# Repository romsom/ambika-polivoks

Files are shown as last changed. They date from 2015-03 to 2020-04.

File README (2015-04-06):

Polivoks voicecard for the Mutable Instruments Ambika synthesizer.

Based on work by Olivier Gillet - http://www.mutable-instruments.net/.

Developed by Krzysztof Iwanowski.

The firmware is released under a GPL3.0 license.

The PCB layouts and schematics are released under a Creative Commons cc-by-sa 3.0 license.

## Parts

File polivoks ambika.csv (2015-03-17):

Parts | Device | Value | Qty
LED1, LED2 | LED3MM |  | 2
JP1, JP3 | Male 1x3 header |  | 2
JP2, JP4 | Female 1x6 header |  | 2
R9, R10, R12, R21 | R | 100k | 4
R1, R15, R39 | R | 10k | 3
R2, R11 | R | 15k | 2
R8, R14 | R | 1k | 2
R13, R19, R22 | R | 2.2k | 3
R34, R37, R38 | R | 220 | 3
R23 | R | 33k | 1
R35, R36 | R | 470 | 2
R6, R7, R18, R20 | R | 47k | 4
R17 | R | 56k | 1
R16 | R | 68k | 1
C3, C5, C6, C7, C8, C9, C13, C14, C16, C17, C18, C23, C24, C25 | Ceramic | 100n | 14
C10 | Ceramic | 100p | 1
C11, C20, C28 | Electrolytic, >= 15V, height <= 7mm | 100u | 3
C26, C27 | Ceramic | 20p | 2
C2, C12 | Ceramic | 33n | 2
C1, C4 | Electrolytic NP, >35V | 4.7u | 2
Q5 | Quartz | 20MHz | 1
Q3, Q4 | 2N3904 NPN |  | 2
Q1, Q2 | 2N3906 PNP |  | 2
IC2 | 4052N |  | 1
IC7 | ATMega328p |  | 1
IC11 | LM13700N |  | 1
IC9, IC10 | LM4250P |  | 2
IC6 | MCP4822 |  | 1
IC5 | TL072P |  | 1
IC1 | TL084P |  | 1
 | DIP8 Socket |  | 4
 | DIP28 Socket |  | 1
 | DIP14 Socket |  | 1
 | DIP16 Socket |  | 2
 | Jumper |  | 2

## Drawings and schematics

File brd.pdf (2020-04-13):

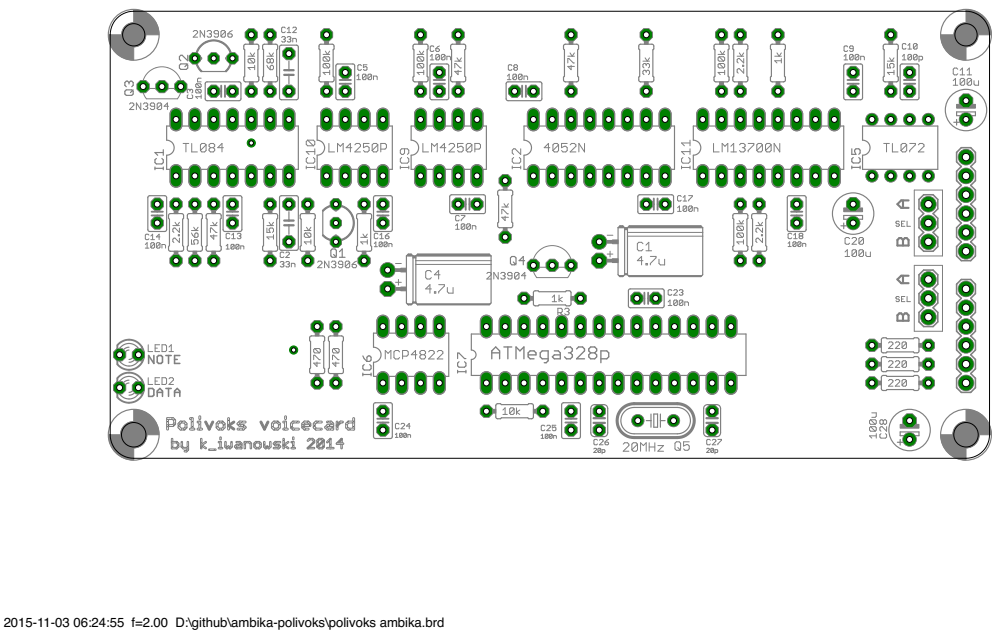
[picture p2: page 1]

2015-11-03 06:24:55 f=2.00 D:\github\ambika-polivoks\polivoks ambika.brd

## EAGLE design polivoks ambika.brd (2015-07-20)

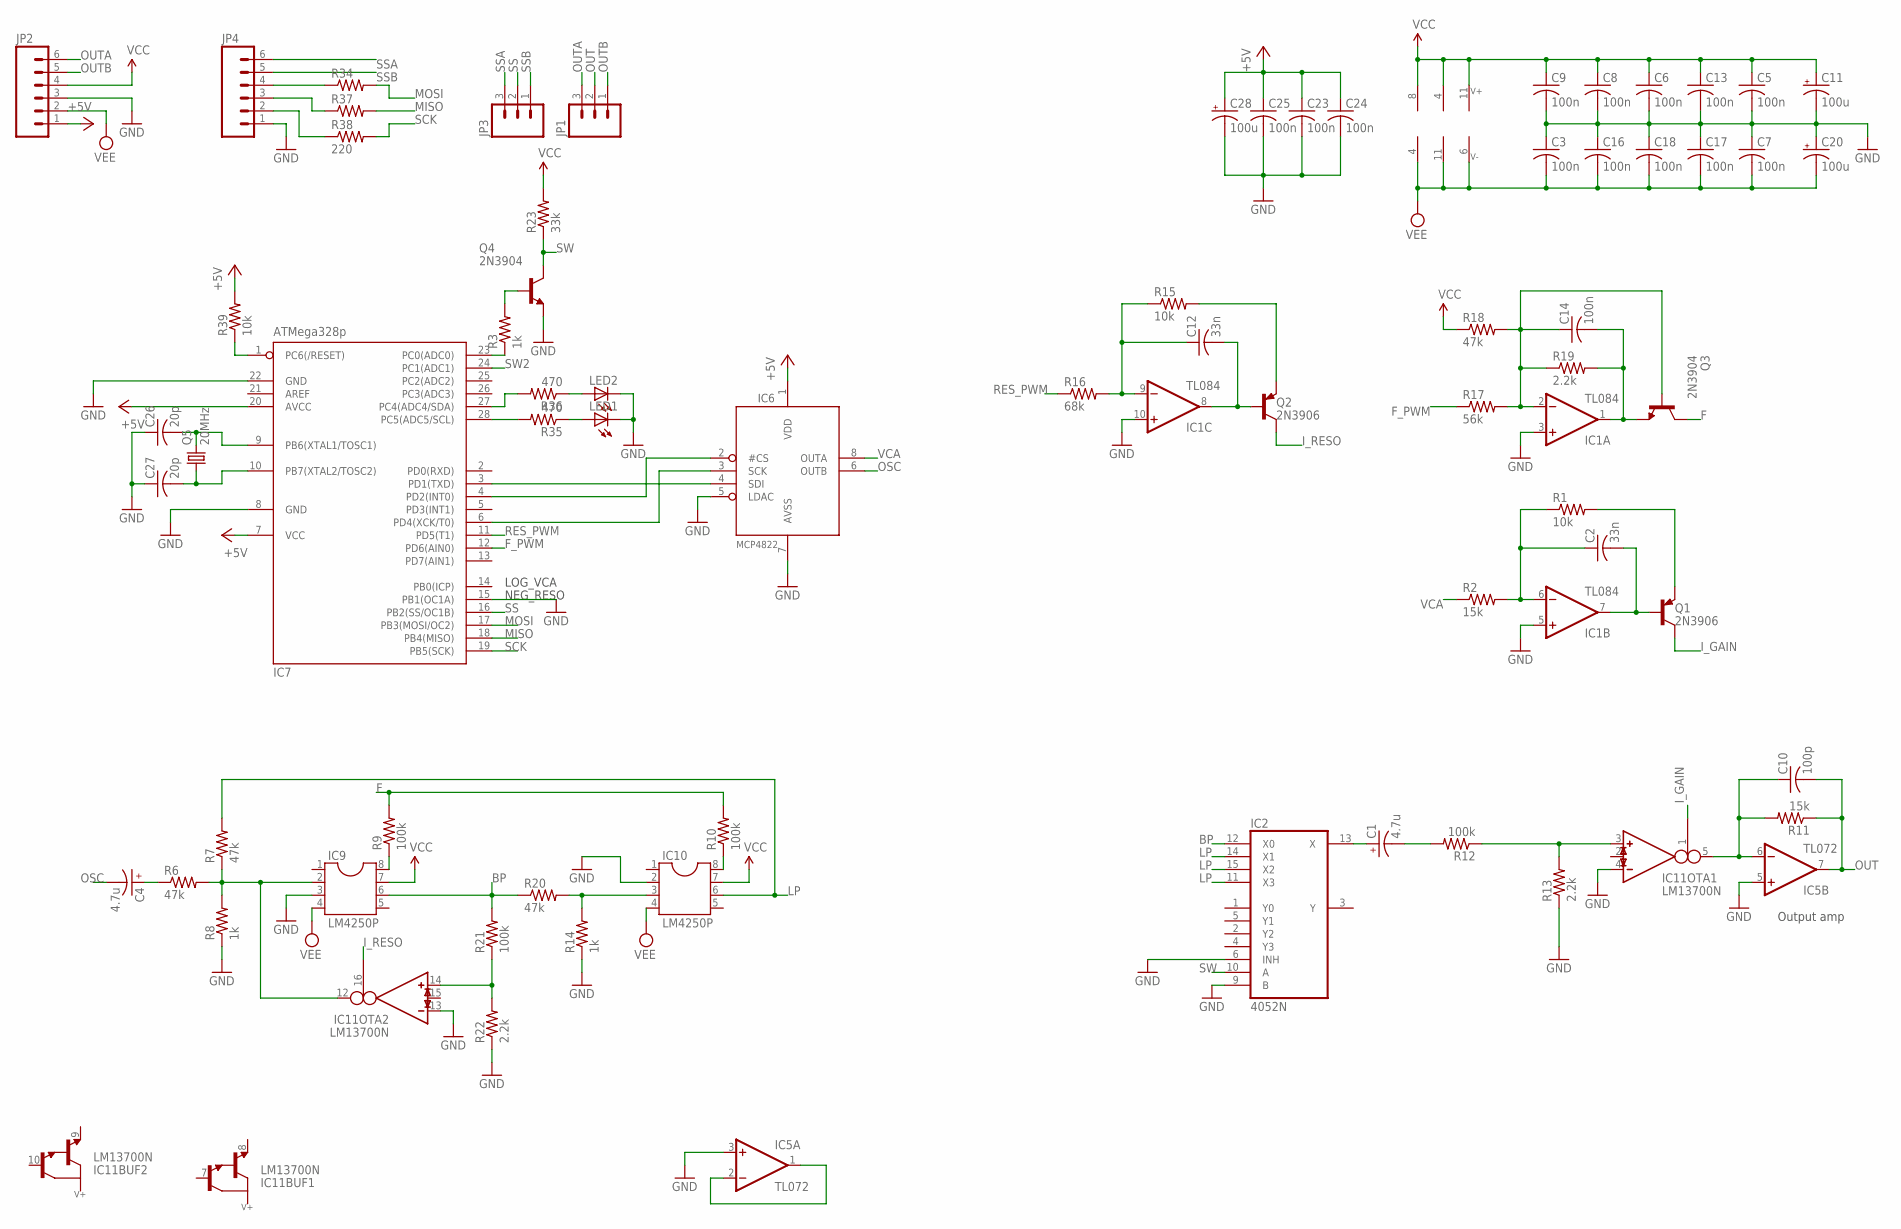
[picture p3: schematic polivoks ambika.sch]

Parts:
C1, C4: 4.7u; E11-6.3
C2, C12: 33n; C050-025X075
C3, C5, C6, C7, C8, C9, C13, C14, C16, C17, C18, C23, C24, C25: 100n; C025-025X050
C10: 100p; C025-025X050
C11, C20, C28: 100u; E2,5-6
C26, C27: 20p; C025-024X044
IC1: TL084; DIL14
IC2: 4052N; DIL16
IC5: TL072; DIL08
IC6: MCP4822; DIL08
IC7: ATMega328p; DIL28-3
IC9, IC10: LM4250P; DIL08
IC11: LM13700N; DIL16
JP1, JP3: M03PTH; 1X03
JP2, JP4: M06SIP; 1X06
LED1, LED2: LED3MM
Q1, Q2: 2N3906; TO92-
Q3, Q4: 2N3904; TO92
Q5: 20MHz; HC49U-V
R1, R15, R39: 10k; 0204/7
R2, R11: 15k; 0204/7
R3, R8, R14: 1k; 0204/7
R6, R7, R18, R20: 47k; 0204/7
R9, R10, R12, R21: 100k; 0204/7
R13, R19, R22: 2.2k; 0204/7
R16: 68k; 0204/7
R17: 56k; 0204/7
R23: 33k; 0204/7
R34, R37, R38: 220; 0204/7
R35, R36: 470; 0204/7

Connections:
+5V: C23.1, C24.1, C25.1, C28.+, IC6.1 (VDD), IC7.7 (VCC), IC7.20 (AVCC), JP2.1, R39.2
BP: IC2.12 (X0), IC9.6, R20.1, R21.2
F: Q3.1 (C), R9.2, R10.2
F_PWM: IC7.12 (PD6(AIN0)), R17.1
GND: C3.1, C5.2, C6.2, C7.1, C8.2, C9.2, C11.-, C13.2, C16.1, C17.1, C18.1, C20.+, C23.2, C24.2, C25.2, C26.1, C27.1, C28.-, IC1.3 (+IN), IC1.5 (+IN), IC1.10 (+IN), IC2.6 (INH), IC2.8 (GND), IC2.9 (B), IC5.3 (+IN), IC5.5 (+IN), IC6.5 (LDAC), IC6.7 (AVSS), IC7.8 (GND), IC7.15 (PB1(OC1A)), IC7.22 (GND), IC9.3, IC10.2, IC11.4 (IN_N), IC11.13 (IN_N), JP2.3, JP4.1, LED1.K (C), LED2.K (C), Q4.3 (E), R8.1, R13.1, R14.1, R22.1
I_GAIN: IC11.1 (I_BIAS), Q1.1 (C)
I_RESO: IC11.16 (I_BIAS), Q2.1 (C)
LP: IC2.11 (X3), IC2.14 (X1), IC2.15 (X2), IC10.6, R7.2
MISO: IC7.18 (PB4(MISO)), R37.2
MOSI: IC7.17 (PB3(MOSI/OC2)), R34.2
unnamed: IC9.2, IC11.12 (OUT), R6.2, R7.1, R8.2
unnamed: C14.2, IC1.1 (OUT), Q3.3 (E), R19.2
unnamed: IC6.4 (SDI), IC7.3 (PD1(TXD))
unnamed: C4.+ (1), R6.1
unnamed: C1.+ (1), IC2.13 (X)
unnamed: IC10.3, R14.2, R20.2
unnamed: LED1.A, R35.1
unnamed: JP4.2, R38.1
unnamed: IC9.8, R9.1
unnamed: LED2.A, R36.1
unnamed: IC7.27 (PC4(ADC4/SDA)), R36.2
unnamed: C1.- (2), R12.2
unnamed: JP4.3, R37.1
unnamed: IC7.1 (PC6(/RESET)), R39.1
unnamed: IC6.3 (SCK), IC7.6 (PD4(XCK/T0))
unnamed: IC6.2 (#CS), IC7.4 (PD2(INT0))
unnamed: IC10.8, R10.1
unnamed: JP4.4, R34.1
unnamed: IC11.14 (IN_P), R21.1, R22.2
unnamed: IC7.28 (PC5(ADC5/SCL)), R35.2
unnamed: Q4.2 (B), R3.2
unnamed: IC5.1 (OUT), IC5.2 (-IN)
unnamed: IC7.23 (PC0(ADC0)), R3.1
unnamed: C12.2, IC1.8 (OUT), Q2.2 (B)
unnamed: C2.2, IC1.7 (OUT), Q1.2 (B)
unnamed: IC11.3 (IN_P), R12.1, R13.2
unnamed: C14.1, IC1.2 (-IN), Q3.2 (B), R17.2, R18.2, R19.1
unnamed: C2.1, IC1.6 (-IN), R1.1, R2.2
unnamed: C12.1, IC1.9 (-IN), R15.1, R16.2
unnamed: Q2.3 (E), R15.2
unnamed: Q1.3 (E), R1.2
unnamed: C10.1, IC5.6 (-IN), IC11.5 (OUT), R11.2
unnamed: C27.2, IC7.10 (PB7(XTAL2/TOSC2)), Q5.1
unnamed: C26.2, IC7.9 (PB6(XTAL1/TOSC1)), Q5.2
OSC: C4.- (2), IC6.6 (OUTB)
OUT: C10.2, IC5.7 (OUT), JP1.2, R11.1
OUTA: JP1.3, JP2.6
OUTB: JP1.1, JP2.5
RES_PWM: IC7.11 (PD5(T1)), R16.1
SCK: IC7.19 (PB5(SCK)), R38.2
SS: IC7.16 (PB2(SS/OC1B)), JP3.2
SSA: JP3.3, JP4.6
SSB: JP3.1, JP4.5
SW: IC2.10 (A), Q4.1 (C), R23.1
SW2: IC7.24 (PC1(ADC1))
VCA: IC6.8 (OUTA), R2.1
VCC: C5.1, C6.1, C8.1, C9.1, C11.+, C13.1, IC1.4 (V+), IC2.16 (VCC), IC5.8 (V+), IC9.7, IC10.7, IC11.11 (V+), JP2.4, R18.1, R23.2
VEE: C3.2, C7.2, C16.2, C17.2, C18.2, C20.-, IC1.11 (V-), IC2.7 (VEE), IC5.4 (V-), IC9.4, IC10.4, IC11.6 (V-), JP2.2

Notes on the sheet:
LOG_VCA
NEG_RESO
Output amp

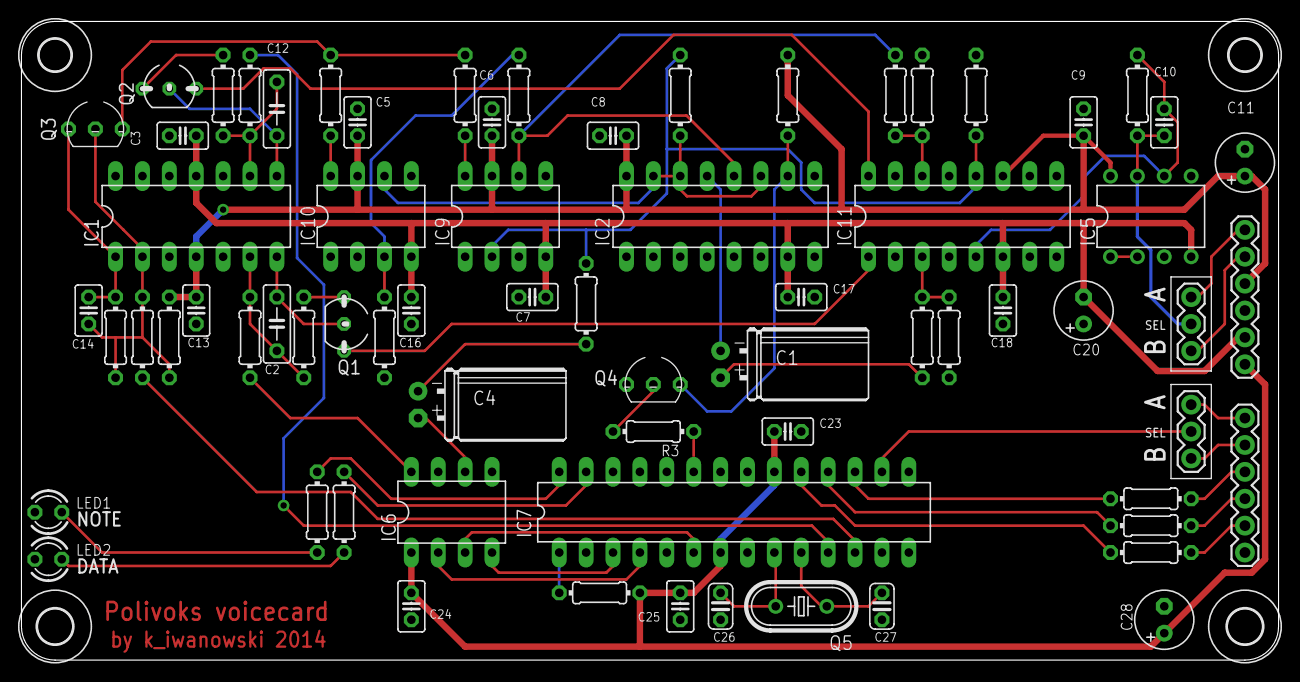
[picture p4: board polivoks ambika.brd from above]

Board: 2 copper layers, 118.7 x 60.3 mm, 74 parts (0 on the bottom side), 57 nets.

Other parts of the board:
U$1, U$2: 3,0
U$4, U$5: 3,3

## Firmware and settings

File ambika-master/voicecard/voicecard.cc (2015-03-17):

// Copyright 2011 Olivier Gillet.
//
// Author: Olivier Gillet (ol.gillet@gmail.com)
//
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

#include <avr/interrupt.h>

#include "voicecard/voicecard.h"

#include "avrlib/boot.h"
#include "avrlib/gpio.h"
#include "avrlib/parallel_io.h"
#include "avrlib/timer.h"

#include "voicecard/audio_out.h"
#include "voicecard/leds.h"
#include "voicecard/resources.h"
#include "voicecard/voice.h"
#include "voicecard/voicecard_rx.h"

using namespace avrlib;
using namespace ambika;

static const uint8_t kPinVcaOut = 3;
static const uint8_t kPinVcfResonanceOut = 5;
static const uint8_t kPinVcfCutoffOut = 6;

PwmOutput<kPinVcfCutoffOut> vcf_cutoff_out;
PwmOutput<kPinVcfResonanceOut> vcf_resonance_out;
PwmOutput<kPinVcaOut> vca_out;

ParallelPort<PortC, PARALLEL_TRIPLE_LOW> vcf_mode;

Gpio<PortB, 0> log_vca;

UartSpiMaster<UartSpiPort0, Gpio<PortD, 2>, 2> dac_interface;

static uint8_t update_vca;
static const uint8_t dac_scale = 16;

ISR(TIMER2_OVF_vect) {
  static uint8_t sample_counter = 0;
  static Word vca_12bits;
  
  if (update_vca) {
    dac_interface.Strobe();
    update_vca = 0;
    dac_interface.Overwrite(vca_12bits.bytes[1]);
    dac_interface.Overwrite(vca_12bits.bytes[0]);
    dac_interface.Wait();
    uint16_t next_vca_value;
    if (log_vca.is_low()) {
      next_vca_value = ambika::ResourcesManager::Lookup<uint16_t, uint8_t>(
          lut_res_vca_linearization,
          voice.vca());
    } else {
      next_vca_value = voice.vca() * dac_scale;
    }
    vca_12bits.value = next_vca_value | 0x1000;
  }
  
  uint8_t sample = audio_buffer.ImmediateRead();
  if (++sample_counter >= voice.crush()) {
    dac_interface.Strobe();
    sample_counter = 0;
    Word sample_12bits;
    sample_12bits.value = (sample * dac_scale) | 0x9000;
    dac_interface.Overwrite(sample_12bits.bytes[1]);
    dac_interface.Overwrite(sample_12bits.bytes[0]);
  }
  voicecard_rx.Receive();
}

// This GPIO is used during development for timing code.
Gpio<PortD, 7> timing_signal;

inline void Init() {
  sei();
  UCSR0B = 0;
  ResetWatchdog();
  
  dac_interface.Init();

  rx_led.set_mode(DIGITAL_OUTPUT);
  note_led.set_mode(DIGITAL_OUTPUT);
  rx_led.Low();
  note_led.Low();
  
  vcf_cutoff_out.Init();
  vcf_resonance_out.Init();
  vca_out.Init();
  vcf_mode.set_mode(DIGITAL_OUTPUT);

  voicecard_rx.Init();
  voice.Init();
  
  log_vca.set_mode(DIGITAL_INPUT);
  log_vca.High();
  dac_interface.Strobe();
  dac_interface.Overwrite(0x10 | 0x0f);
  dac_interface.Overwrite(0xff);
  
  // Successful boot!
  if (eeprom_read_byte(kFirmwareUpdateFlagPtr) != FIRMWARE_UPDATE_DONE) {
    eeprom_write_byte(kFirmwareUpdateFlagPtr, FIRMWARE_UPDATE_DONE);
  }
  
  // Initialize all the PWM outputs to 39kHz, phase correct mode.
  Timer<0>::set_prescaler(1);
  Timer<0>::set_mode(TIMER_PWM_PHASE_CORRECT);
  Timer<1>::set_prescaler(1);
  Timer<1>::set_mode(TIMER_PWM_PHASE_CORRECT);
  Timer<2>::set_prescaler(1);
  Timer<2>::set_mode(TIMER_PWM_PHASE_CORRECT);
  Timer<2>::Start();
}

static uint8_t filter_mode_bytes[] = { 0, 1, 2, 3 };
static uint8_t leds_timeout = 0;

int main(void) {
  Init();
  // For testing only...
  // voice.Trigger(60 * 128, 100, 0);
  while (1) {
    // Check if there's a block of samples to fill.
    if (audio_buffer.writable() >= kAudioBlockSize) {
      voicecard_rx.TickRxLed();
      voice.ProcessBlock();
      vcf_cutoff_out.Write(voice.cutoff());
      vcf_resonance_out.Write(voice.resonance());
      vcf_mode.Write(filter_mode_bytes[voice.patch().filter[0].mode]);
      update_vca = 1;
    }
    voicecard_rx.Process();
  }
}

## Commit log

2015-03-17 Added the firmware
    [nunchuk-v01.brd, nunchuk-v01.sch, polivoks ambika.csv]
2015-07-20 Added a resistor to limit the current on BP mode
    [polivoks ambika.brd, polivoks ambika.sch]

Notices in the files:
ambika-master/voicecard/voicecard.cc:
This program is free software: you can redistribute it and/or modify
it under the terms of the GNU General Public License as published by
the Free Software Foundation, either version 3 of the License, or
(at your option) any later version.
